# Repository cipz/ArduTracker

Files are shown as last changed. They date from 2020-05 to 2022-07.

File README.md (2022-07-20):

# ArduTracker



#### Developers

- Ciprian Voinea
- Federico Carboni
- Mariano Sciacco
- Prof. Palazzi

# Board

### Esp32 Circuit board

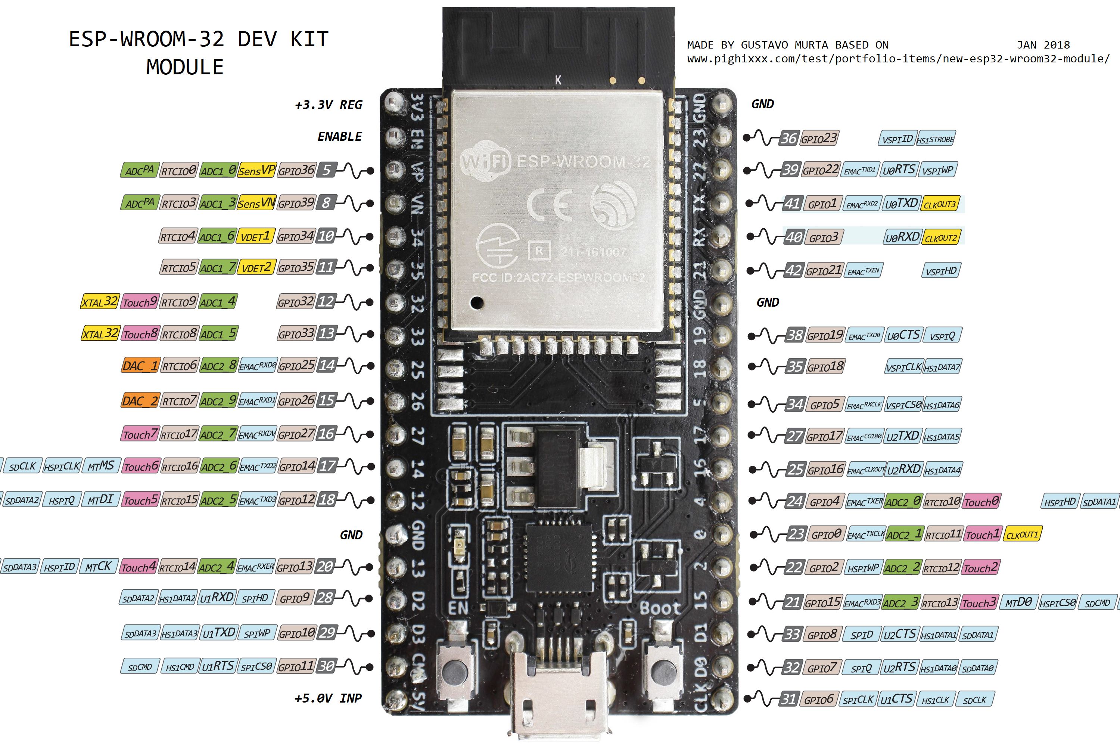
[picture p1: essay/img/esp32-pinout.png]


### Firmware

Arduino IDE + Platformio

#### Additional libraries
- [ArduinoJSON v6](https://arduinojson.org/v6/)

### Circuit

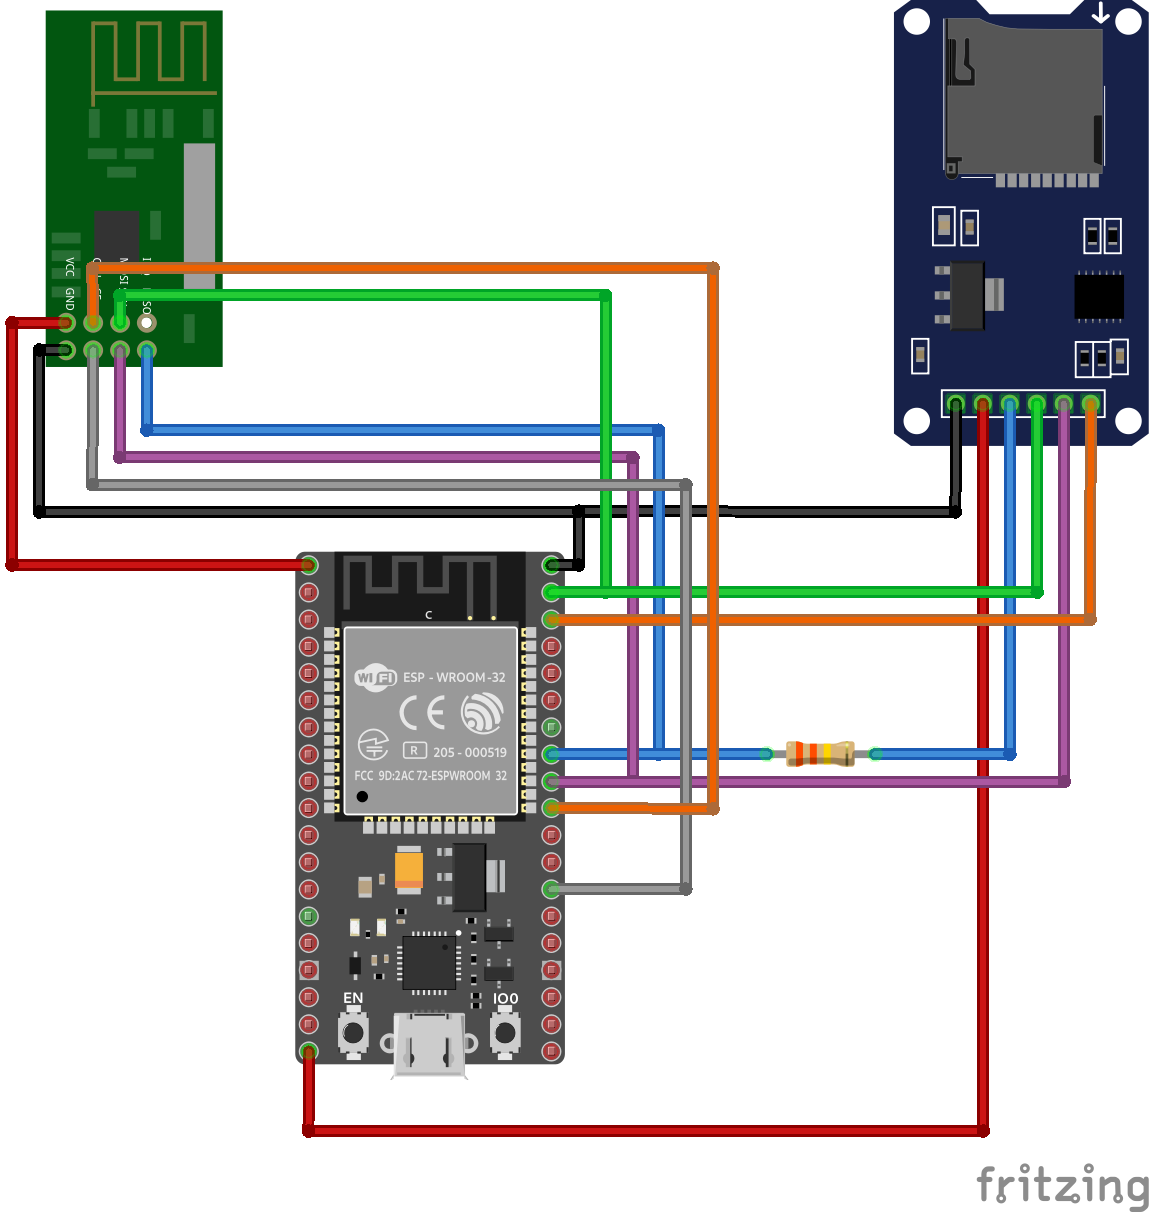
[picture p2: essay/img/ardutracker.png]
circuit


### SPI devices

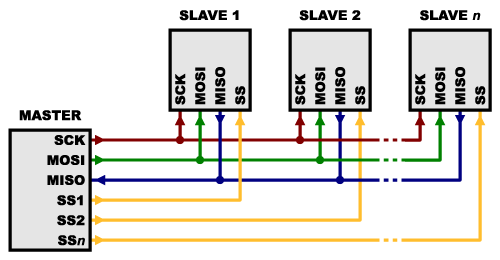
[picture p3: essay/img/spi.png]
spi


### Connecting nRF24L01 to the ESP32

<p align="center">
  <table align="center">
    <tr>
      <td>
        <table style="text-align:center">
          <tr style="font-weight: bold;">
            <td>nRF24L01</td>
            <td>ESP32</td>
          </tr>
          <tr>
            <td>GND</td>
            <td>GND</td>
          </tr>
          <tr>
            <td>VCC</td>
            <td>3.3V</td>
          </tr>
          <tr>
            <td>CE</td>
            <td>D4</td>
          </tr>
          <tr>
            <td>CSN</td>
            <td>D5</td>
          </tr>
          <tr>
            <td>SCK</td>
            <td>D18</td>
          </tr>
          <tr>
            <td>MOSI</td>
            <td>D23</td>
          </tr>
          <tr>
            <td>MISO</td>
            <td>D19</td>
          </tr>
        </table>
      </td>
      <td>
        <p align="center">
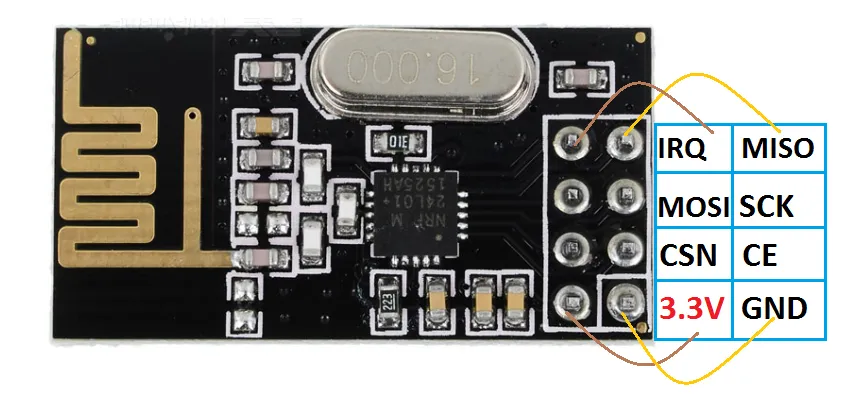
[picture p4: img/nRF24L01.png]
          
        </p>
      </td>
    </tr>
  </table>
</p>

### Connecting MicroSD Module to the ESP32

To connect the SD Module I have adapted a simple Arduino example:

<p align="center">
  <table align="center">
    <tr>
      <td>
        <table style="text-align:center">
          <tr style="font-weight: bold;">
            <td>MicroSD Module</td>
            <td>ESP32</td>
          </tr>
          <tr>
            <td>GND</td>
            <td>GND</td>
          </tr>
          <tr>
            <td>VCC</td>
            <td>5V or 3.3V</td>
          </tr>
          <tr>
            <td>CS</td>
            <td>D22</td>
          </tr>
          <tr>
            <td>SCK</td>
            <td>D18</td>
          </tr>
          <tr>
            <td>MOSI</td>
            <td>D23</td>
          </tr>
          <tr>
            <td>MISO</td>
            <td>D19</td>
          </tr>
        </table>
      </td>
      <td align="center">
        <p align="center">
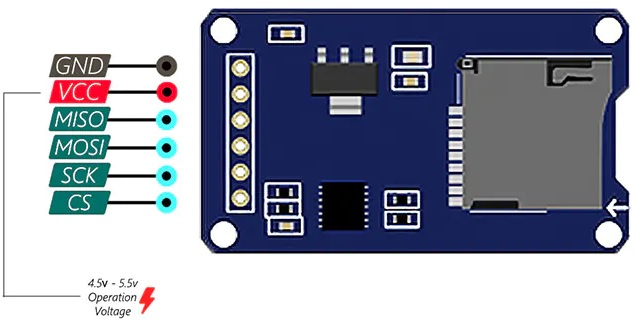
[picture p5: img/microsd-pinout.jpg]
          
        </p>
      </td>
    </tr>
  </table>
</p>

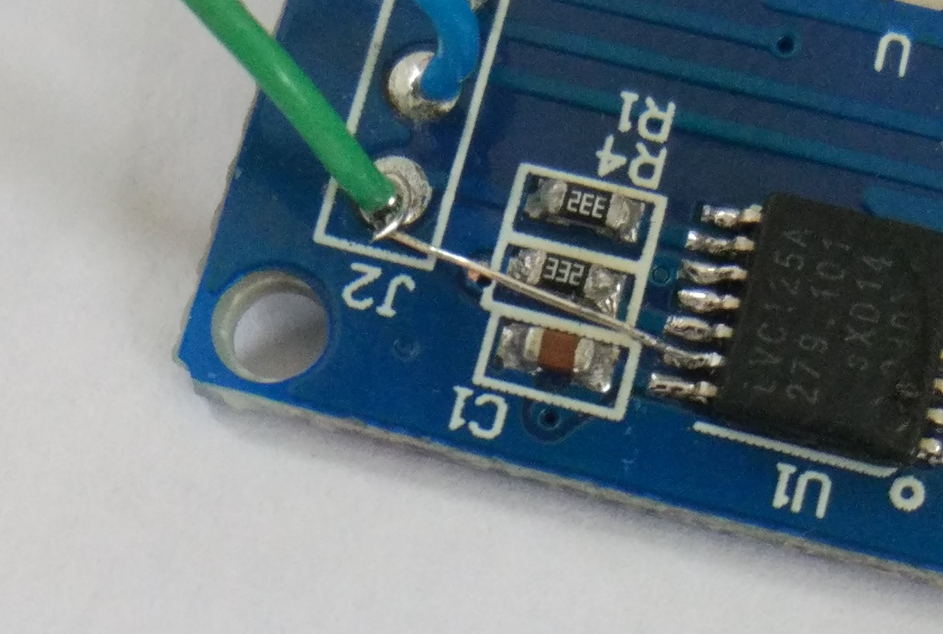
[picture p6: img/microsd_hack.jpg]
Microsd-hack


# Server

## Raspberry Pi and MQTT server
The Mosquitto MQTT server can be set on a Raspberry Pi in the network and it uses IBM's Node-Red.
To configure it I have followed [this](https://randomnerdtutorials.com/esp32-mqtt-publish-subscribe-arduino-ide/) tutorial.

## Docker

To setup the entire server part of the ardutracker project, you need to have installed Docker with docker-compose in a x86_64 capable machine with at least 1GB of ram a single core CPU. 

Move to the `/ArduTrackerServer/` directory and type in a terminal `docker-compose up -d`.
After that, you can stop all the services using `docker-compose down`, always in the same directory.

### Useful links:

#### Tutorials
- [Communication nRF24L01 avec cartes ESP32 et ESP8266 ](http://electroniqueamateur.blogspot.com/2019/12/communication-nrf24l01-avec-cartes.html?m=0)
- [Interfacing Micro SD Card Module with Arduino](https://lastminuteengineers.com/arduino-micro-sd-card-module-tutorial/)
- [ESP32 MQTT – Publish and Subscribe with Arduino IDE](https://randomnerdtutorials.com/esp32-mqtt-publish-subscribe-arduino-ide/)

#### Circuit
- [ESP32 Fritzing file](https://forum.fritzing.org/t/esp32s-hiletgo-dev-boad-with-pinout-template/5357?u=steelgoose)

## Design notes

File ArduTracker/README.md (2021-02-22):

# Project Notes

- SD card adapter requires 5v instaed of 3.3volt, otherwise it does not work properly ([Issue reference](https://rntlab.com/question/card-mount-failed/))

### Debugging MQTT

- Install this software on your PC and connect to mqtt://ardutracker.debug.ovh:21883 ([Mqtt Explorer](http://mqtt-explorer.com/))

#### Upload ports in MacOS

Ignore this, just for developers:

- usb 2: `pio run -t upload --upload-port /dev/cu.usbserial-0001`

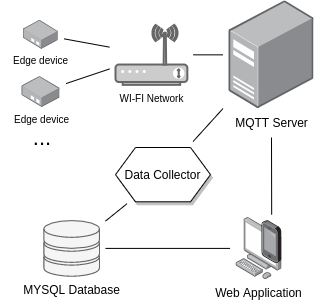
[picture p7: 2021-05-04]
essay/schemas/architecture-schema.png

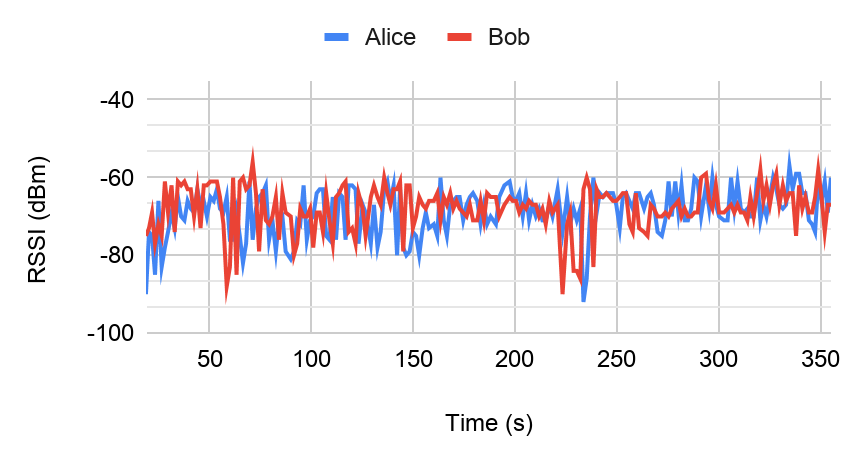
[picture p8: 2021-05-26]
essay/img/ble-indoor-5m.png

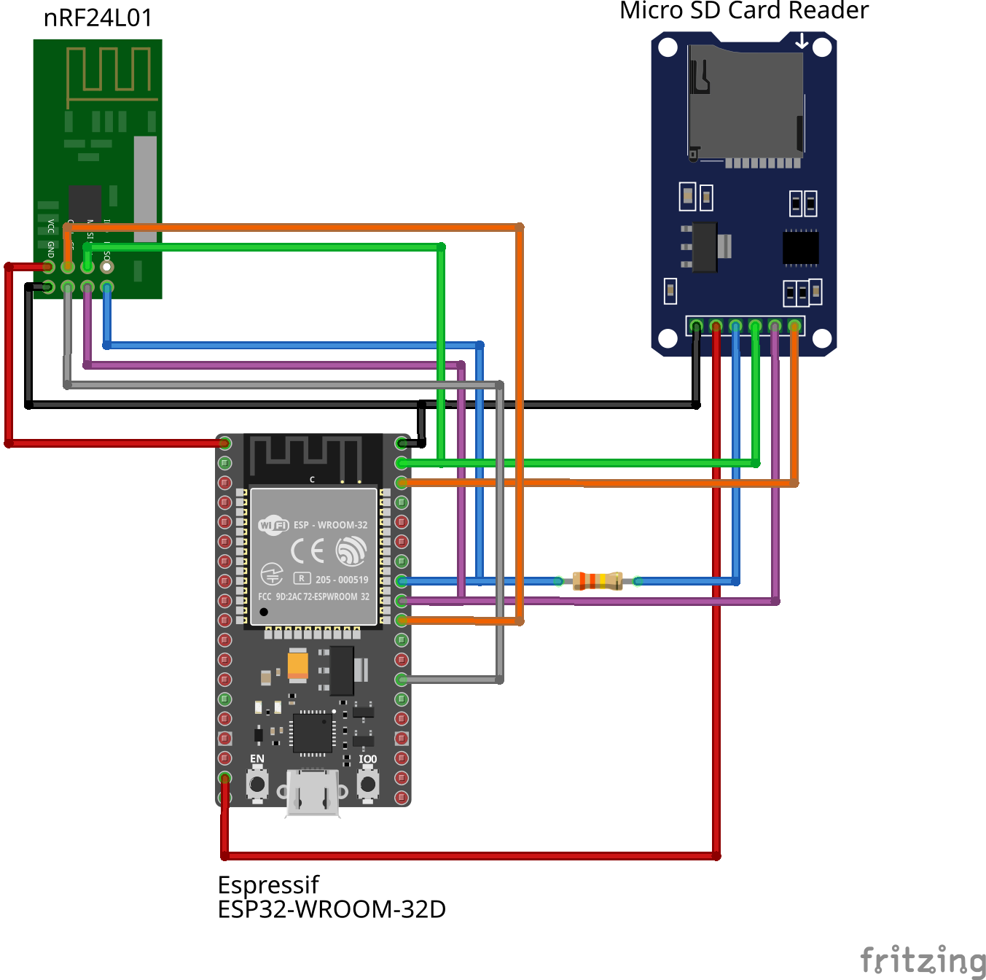
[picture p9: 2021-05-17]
essay/img/ardutracker-label.png

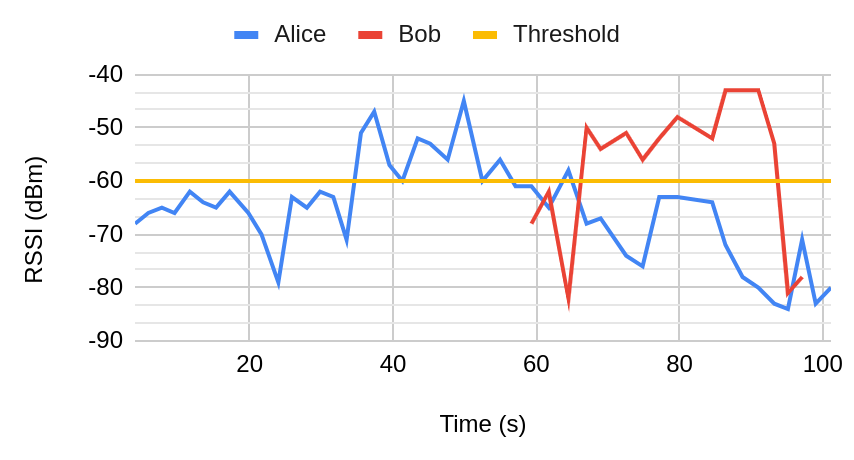
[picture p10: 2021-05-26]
essay/img/ble-moving-station-indoor-outdoor.png

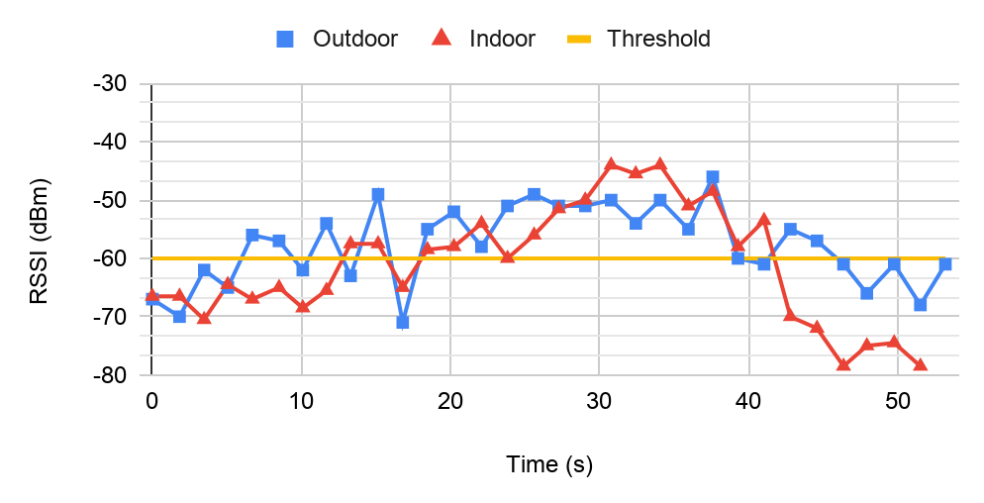
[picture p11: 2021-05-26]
essay/img/ble-sta-moving.png

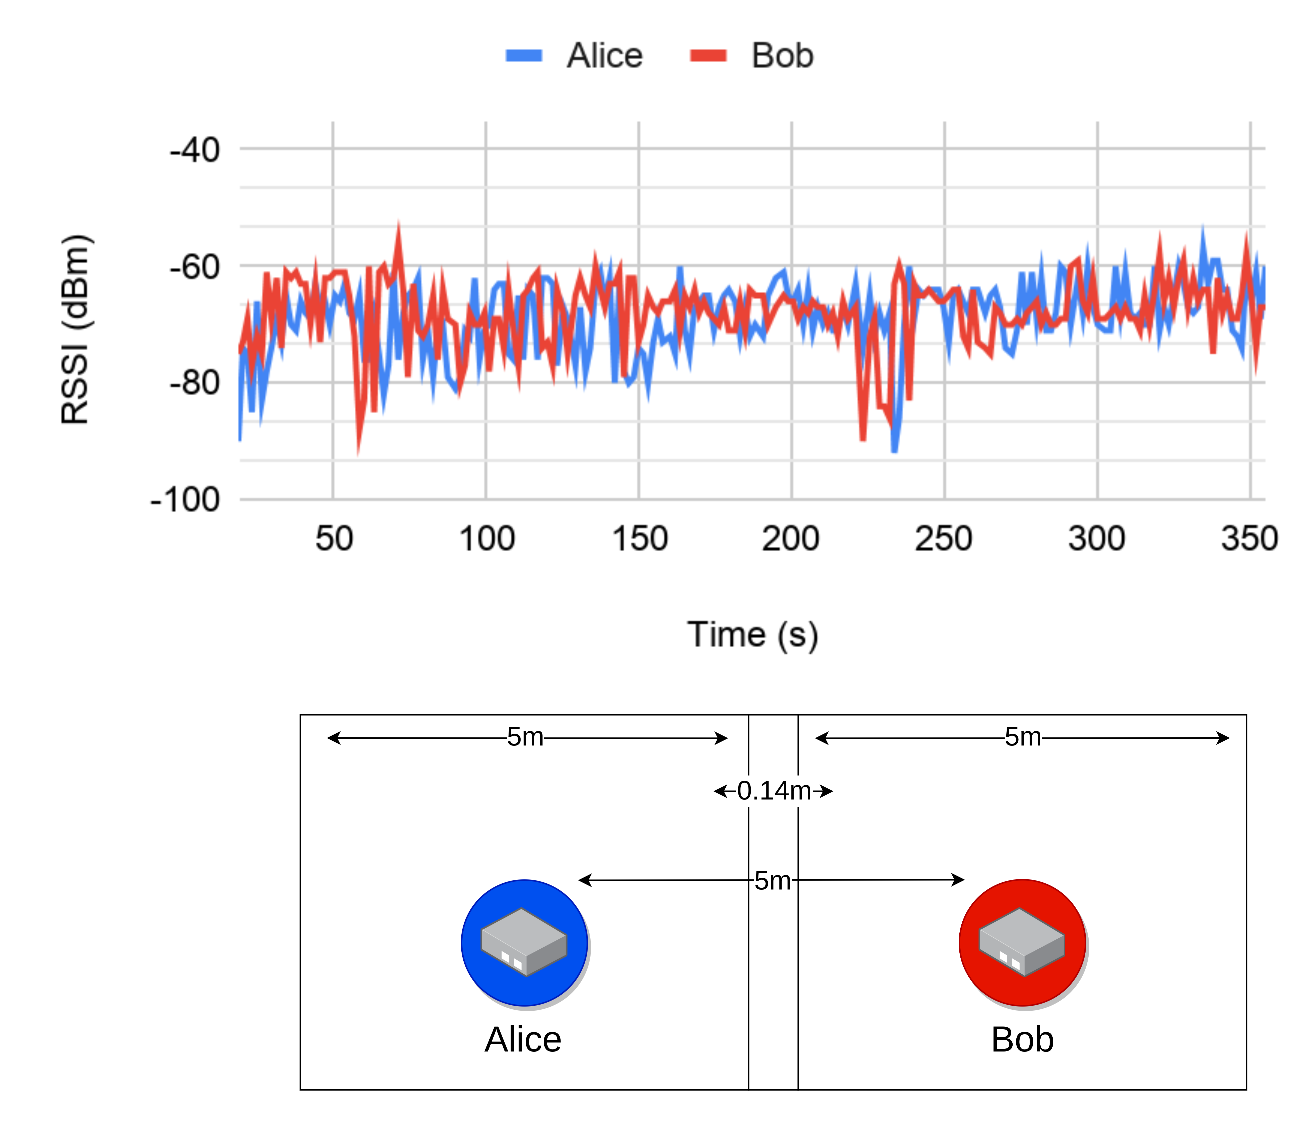
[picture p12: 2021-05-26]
essay/schemas/graph-5m-indoor-ble.png

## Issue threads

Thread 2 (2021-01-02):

Componenti di progetto (backend server + frontend)

Maxelweb, 2021-01-02:
## Link utili

**Link PHPMyAdmin**: http://phpmyadmin.ardutracker.debug.ovh
**Connessione Database**: http://database.ardutracker.debug.ovh:3306
**Link Ardutracker**: http://ardutracker.debug.ovh
**Link Portainer (Docker)**: http://portainer.ardutracker.debug.ovh

## Lista dei componenti

- [x] MQTT server su un container docker
- [x] Generatore di messaggi randomici sul server MQTT
- [x] MQTT subscriber per salvare i messaggi dal topic al database
- [x] Interfaccia grafica (da decidere insieme il tipo di framework, etc.)
- [x] Database MYSQL

## Database

**User**: `admin_ardutrack`
**Password**:  `1q9p7lETVi`
**Database**: `ardutrackerdb`
**IP**: `database.ardutracker.debug.ovh`

## Mosquitto (MQTT server broker)

**Listener:** ardutracker.debug.ovh:21883
**Extra-listener:** ardutracker.debug.ovh:29001

Closed 2022-07-20.

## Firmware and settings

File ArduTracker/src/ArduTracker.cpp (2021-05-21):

/*
 *  ARDUTRACKER BOARD (2020 - 2021)
 *  -----------------
 *  Wireless Networks for mobile applications, UniPD
 *  --------
 *  Created by Ciprian Voinea
 *  Edited by Federico Carboni and Mariano Sciacco
*/

// --------------------------------------- Static config

#define RANDOM_TX_MILLS_MIN 2000
#define RANDOM_TX_MILLS_MAX 4000
#define RANDOM_RX_MILLS_MIN 3000
#define RANDOM_RX_MILLS_MAX 6000
#define SERIAL_BAUD_RATE 9600
#define MAX_WIFI_RECON_COUNT 5
#define RESTART_SECONDS 10
#define BLE_PREFIX "AT_"

// Debug modes

#define DEBUG_MODE 1
#define SD_DEBUG_MODE 0
#define STATS_DEBUG_MODE 1

// --------------------------------------- Initialization

#include <SPI.h>
#include <PubSubClient.h>
#include <time.h>
#include <ArduinoJson.h>
#include <LinkedList.h>
#include <WiFi.h>

bool wifiTransmission;
int lastWifiSendTime;
int sendDataCount;

struct Params {
  // WiFi
  char ssid[50];
  char password[50];
//   int wifi_send_interval;
  // nRF24L01
  char my_id[15];
  byte broadcast_io_addr[15];
  // MQTT
  char in_topic[32];
  char out_topic[32];
  char mqtt_server[32]; //FIX: Expanded to allow hostnames
  // Other
  int friendly_freshness;
  // Radio mode
  char radio_mode[15];
  bool station_mode;
  int send_data_cycles;
  int ble_threshold;
  int wifi_kbps;
  int scan_duration;
  int cycles_delay;
};
Params params;
double stats[2] = {0, 0};

WiFiClient espClient;
PubSubClient client(espClient);

#include "at_log.h"
#include "at_utils.h"
#include "abstract_radio.h"
#include "at_nrf24l01.h"
#include "at_ble.h"
#include "at_wifi.h"

LinkedList<Log>* friendList;
#include "at_sd.h"

SDController* sdCrtl;
#include "at_mqtt.h"

AbsRadioController* radioCtrl;
WiFiController* wifiCtrl;
MQTTController* mqttCtrl;


// --------------------------------------- Initial Setup
void setup() {
    Serial.begin(SERIAL_BAUD_RATE);
    Serial.println("Booting device...");

    pinMode(CS_PIN, OUTPUT);
    pinMode(CE_PIN, OUTPUT);

    friendList = new LinkedList<Log>();

    sdCrtl = new SDController();
    wifiCtrl = new WiFiController();
    mqttCtrl = new MQTTController();

    sdCrtl->init();
    sdCrtl->listContent();
    sdCrtl->acquireParams();
    sdCrtl->initLog();
    SDController::populateFromCache();
    delay(100);

    // Mode switcher 
    if(strcmp(params.radio_mode, "WIFI") == 0)
        radioCtrl = new RadioController();
    else if(strcmp(params.radio_mode, "BLE") == 0)
        radioCtrl = new BLEController();
    else {
        Serial.print("Radio mode not found! Using Radio WIFI as default..");
        strlcpy(params.radio_mode, "WIFI", sizeof(params.radio_mode));
        radioCtrl = new RadioController();
    }

    radioCtrl->init();
    wifiCtrl->init();
    mqttCtrl->init();
    sendDataCount = 0;

    Serial.println("Boot sequence finished correctly!");
    delay(100);
}

// --------------------------------------- Loop operations
void loop() {

    stats[0]=0, stats[1]=0;

    Serial.println("\n\n-- -- -- NEW LOOP CYCLE -- -- --\n");

    if(SD_DEBUG_MODE) 
        sdCrtl->listContent();

    //-------------------- Connect to WiFi and reach new Configuration
    
    wifiCtrl->connect();
    mqttCtrl->connect();
    
    if(WiFi.isConnected() && !mqttCtrl->isSubscribed()) {
        // Subscribe to params configuration topic
        String configTopic = params.in_topic + WiFi.macAddress();
        mqttCtrl->subscribe(configTopic.c_str(), sdCrtl);
        Serial.printf(
            "\nSubscribed to: %s\n", 
            configTopic.c_str());
    }


    //-------------------- Send data to MQTT

    if(WiFi.isConnected() && sendDataCount >= params.send_data_cycles) {
        
        Serial.printf(
            "\nSending from CACHE to %s with topic %s", 
            params.mqtt_server, 
            params.out_topic);

        
        File sessionLogFile = SD.open(SESSION_FILE, FILE_READ);
        int inputChar = sessionLogFile.read();
        int strIndex = 0;
        char inputStr[512];

        Serial.println("\nSending:");

        while(inputChar != EOF) {
            if(inputChar != '\n') {
                inputStr[strIndex] = inputChar;
                strIndex++;
                inputStr[strIndex] = '\0';
            }
            else { // Each line
                Serial.println(inputStr);
                mqttCtrl->publish(params.out_topic, inputStr);
                delay(50);
                strIndex = 0;
            }
            inputChar = sessionLogFile.read();
        }

        Serial.printf("\nAll records have been sent to %s \n", params.mqtt_server);
        sessionLogFile.close();
        sdCrtl->clearFile(SESSION_FILE);
        sendDataCount = 0;
    }
    else {
        sendDataCount++;
    }

    // lastWifiSendTime = millis(); // unused

    // -------------------- Receive radio message
    LinkedList<Log>* tmpFriendList = radioCtrl->scan();

    if(DEBUG_MODE)
        Utils::printList(friendList, "[DEBUG-BEFORE]");
    Utils::updateFriendList(friendList, tmpFriendList);
    if(DEBUG_MODE)
        Utils::printList(friendList, "[DEBUG-AFTER]");
   
    // -------------------- Save list to SD 

    Serial.print("Saving exposure sessions to SD . . . \n");

    String serializedMsg = "";
    
    if(friendList->size() > 0) {

        for(int i = 0; i < friendList->size(); ++i){
            if(friendList->get(i).is_from_cache || difftime(time(nullptr), friendList->get(i).last_exposure_time) * 1000 > params.friendly_freshness) {
                String msg = friendList->get(i).serializeMqtt(params.my_id);
                if(DEBUG_MODE)
                    Serial.println(msg);

                sdCrtl->saveConcludedSession(msg);
                friendList->remove(i);
                // Salvo in session e in perm
            }
            else {
                serializedMsg += friendList->get(i).serializeLocal() + "\n"; 
            }
        }

        sdCrtl->saveCurrentSessions(serializedMsg);
        Serial.print("Saved!");
    }
    else 
        Serial.print("Nothing new to save.");
    
    tmpFriendList->clear();

    //-------------------- Send radio message

    Serial.println(params.station_mode);
    if(!params.station_mode) {
        radioCtrl->send();
    }

    if(STATS_DEBUG_MODE) {
        Serial.printf("STATS: %d ---> %d \n", strcmp(params.radio_mode, "BLE"), radioCtrl->getStatsRx());

        if(strcmp(params.radio_mode,"WIFI") == 0)
            sdCrtl->saveInStats(radioCtrl->getStatsTx(), radioCtrl->getStatsRx());
        else if(strcmp(params.radio_mode, "BLE") == 0 && stats[0] && stats[1])
            sdCrtl->saveInStats(stats[0], stats[1]);
        //     sdCrtl->saveInStats(radioCtrl->getStatsRx());
    }
    
    if(DEBUG_MODE)
        Serial.printf("Cycles delay: %d \n", params.cycles_delay);
    delay(params.cycles_delay);
}

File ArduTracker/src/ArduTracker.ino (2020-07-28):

#define SERIAL_BAUD_RATE 9600
#define DEBUG_MODE 0
#define MAX_WIFI_RECON_COUNT 5
#define RESTART_SECONDS 10
#define RANDOM_TX_MILLS_MIN 2000
#define RANDOM_TX_MILLS_MAX 4000
#define RANDOM_RX_MILLS_MIN 3000
#define RANDOM_RX_MILLS_MAX 6000

#include <SPI.h>
#include <ArduinoJson.h>

#include <PubSubClient.h>
#include <time.h>

#include "at_utils.h"

#include "at_list.h"
List * friend_list;

struct Params {
  // WiFi
  char ssid[50];
  char password[50];
  int wifi_send_interval;
  // nRF24L01
  char my_id[15];
  byte broadcast_io_addr[15];
  // MQTT
  char in_topic[25];
  char out_topic[25];
  char mqtt_server[16];
  // Other
  int friendly_freshness;
};
Params params;

#include "at_nrf24l01.h"
#include "at_sd.h"
#include "at_wifi.h"

bool wifi_transmission;
int last_wifi_send_time;

WiFiClient espClient;
PubSubClient client(espClient);

// -- -- -- -- -- -- -- -- -- -- -- -- -- -- -- -- -- -- -- -- -- -- -- -- -- -- -- -- -- -- -- --

void setup() {

  Serial.begin(SERIAL_BAUD_RATE);
  Serial.println("Booting device");

  pinMode(CS_PIN, OUTPUT);
  pinMode(CE_PIN, OUTPUT);

  //\\//\\//\\//\\//\\//\\//\\//\\//\\//\\

  // SD setup
  Serial.print("Setting up SD card: ");

  if (init_sd())
    Serial.println("OK");
  else {
    Serial.println("ERROR");
    Serial.println("Rebooting in 10 seconds");
    restart(RESTART_SECONDS);
  }

  Serial.println("SD card contents: ");
  listFiles();

  Serial.print("Acquiring parameters from SD card: ");
  if (load_sd_params())
    Serial.println("OK");
  else {
    Serial.println("ERROR");
    Serial.println("Rebooting in 10 seconds");
    restart(RESTART_SECONDS);
  }

  Serial.println("Creating log files");
  init_log_files();
  Serial.println("Log files correctly created!");

  delay(100);

  //\\//\\//\\//\\//\\//\\//\\//\\//\\//\\

  // Radio setup
  Serial.println("Initializing radio functions");
  init_radio();

  //\\//\\//\\//\\//\\//\\//\\//\\//\\//\\

  // Received data list setup
  friend_list = new List();

  //\\//\\//\\//\\//\\//\\//\\//\\//\\//\\

  // WiFi + time
  Serial.println("Initializing WiFi");
  WiFi.mode(WIFI_STA);
  last_wifi_send_time = 1000000000;
  wifi_transmission = true;
  // timezone is 2
  configTime(2 * 3600, 0, "pool.ntp.org", "time.nist.gov");

  //\\//\\//\\//\\//\\//\\//\\//\\//\\//\\

  // MQTT
  Serial.println("Initializing MQTT");
  client.setServer(params.mqtt_server, 1883);

  //\\//\\//\\//\\//\\//\\//\\//\\//\\//\\

  if (DEBUG_MODE) {

    Serial.println("Initializing DEBUG_MODE variables");

    // Radio
    const byte broadcastAddress[5] = {'R', 'x', 'T', 'x', '0'};
    radio.openWritingPipe(broadcastAddress);
    radio.openReadingPipe(1, broadcastAddress);
    strlcpy(params.my_id, "IRON MAN", sizeof(params.my_id));
    params.friendly_freshness = 5000;

    // WiFi
    strlcpy(params.ssid, "NETGEAR66", sizeof(params.ssid));
    strlcpy(params.password, "elatedowl630", sizeof(params.password));
    wifi_transmission = false;

    // MQTT
    strlcpy(params.mqtt_server, "192.168.0.13", sizeof(params.mqtt_server));

  }

  Serial.println("Boot sequence finished correctly!");
  delay(100);

}

// -- -- -- -- -- -- -- -- -- -- -- -- -- -- -- -- -- -- -- -- -- -- -- -- -- -- -- -- -- -- -- --

void loop() {

  Serial.println("\n\n\n\n\n- - - - - NEW LOOP CYCLE\n");

  if (DEBUG_MODE) {
    Serial.println("SD card contents: ");
    listFiles();
  }

  // Generating random times
  int random_tx_time = random(RANDOM_TX_MILLS_MIN, RANDOM_TX_MILLS_MAX);
  int random_rx_time = random(RANDOM_RX_MILLS_MIN, RANDOM_RX_MILLS_MAX);

  // Serial.println("\n -- -- -- -- -- -- -- -- \n");

  // Radio receiving
  int start_rx_time = millis();
  radio.startListening();
  List * tmp_friend_list = new List();
  int rx_count = rx_data(random_rx_time, tmp_friend_list);

  Serial.print("Received ");
  Serial.print(rx_count);
  Serial.println(" messages");

  // -----------------------------------

  // Saving files to sd card
  Serial.println("friend_list->printNodes();");
  friend_list->printNodes();

  Serial.println("tmp_friend_list->printNodes();");
  tmp_friend_list->printNodes();

  Serial.println("removing duplicates from tmp_friend_list");
  tmp_friend_list->removeDuplicates();
  
  friend_list->appendList(tmp_friend_list);
  friend_list->compactList(params.friendly_freshness);

  Serial.println("tmp_friend_list->printNodes();");
  tmp_friend_list->printNodes();
  Node * tmp_friend = tmp_friend_list->first;
  while (tmp_friend) {

    if (WiFi.status() != WL_CONNECTED)
      tmp_friend->seen_time = time(nullptr);

    // Creating string to save in file
    String current_message = "{\
\"my_id\" : \"" + (String)params.my_id + "\", \
\"friend_id\" : \"" + (String)tmp_friend->friend_id + "\", \
\"seen_millis\" : \"" + (String)tmp_friend->seen_millis + "\", \
\"seen_time\" : \"" + (String)tmp_friend->seen_time + "\" \
}";

    Serial.println("Saving to sd card... ");
    Serial.println(current_message);
    save_in_log(current_message);

    Serial.println(tmp_friend->seen_millis);
    tmp_friend = tmp_friend->next;

  }

  // Removing tmp_list
  tmp_friend_list->deleteList();

  // -----------------------------------

  delay(50);

  Serial.println("\n -- -- -- -- -- -- -- -- \n");

  // Radio sending
  int start_tx_time = millis();
  radio.stopListening();
  Serial.print("Sending : '");
  Serial.print(params.my_id);
  Serial.println("'");
  int tx_count = tx_data(random_tx_time);
  Serial.print("Sent ");
  Serial.print(tx_count);
  Serial.println(" messages");

  Serial.println("\n -- -- -- -- -- -- -- -- \n");

  if (wifi_transmission) {
    // Sending messages over WiFi
    if (millis() - last_wifi_send_time > params.wifi_send_interval) {
      if (WiFi.status() != WL_CONNECTED) {

        Serial.println("Scanning available networks...");
        if (wifi_scan(params.ssid)) {

          Serial.println("Setting up WiFi connection.");
          int wifi_recon_count = 0;
          Serial.print("Attempting connection");
          while ((WiFi.status() != WL_CONNECTED) and (wifi_recon_count < MAX_WIFI_RECON_COUNT)) {
            Serial.print(".");
            WiFi.begin(params.ssid, params.password);
            wifi_recon_count++;
            delay(50);
          }

          if (wifi_recon_count < MAX_WIFI_RECON_COUNT) {
            Serial.println("WiFi connected successfully");
            Serial.print("IP address: ");
            Serial.println(WiFi.localIP());
          } else {
            Serial.println("Exceeded connection tries");
          }

        } else {
          Serial.print(params.ssid);
          Serial.println(" not in range.");
        }
      } else {
        Serial.println("WiFi already connected");
      }

      if (WiFi.status() != WL_CONNECTED) {
        Serial.print("Error connecting to ");
        Serial.println(params.ssid);

      } else {

        Serial.print("Connected to ");
        Serial.println(params.ssid);

        // -----------------------------------
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

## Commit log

2020-05-03 Added circuit
    [ArduTracker.fzz]
2020-05-05 Updated circuit
    [ArduTracker_Arduino_UNO.fzz, ArduTracker_esp32.fzz]
2020-05-05 Circuit fix
    [ArduTracker_esp32.fzz]
2020-05-06 Solved SD problem (add / in front of files)
    [ArduTracker.ino]
2020-05-07 VCC of MicroSD to 3.3V
    [ArduTracker_esp32.fzz]
2020-05-07 Removed UNO circuit
    [ArduTracker_Arduino_UNO.fzz]
2020-05-09 Trying to fix problems with SD Card
    [ArduTracker.ino]
2020-05-17 Double Linked List not working
    [ArduTracker.ino]
2020-07-28 write on sd not working
    [ArduTracker.ino]
2021-02-02 Edit circuit composition
    NOTE: On the 3.3v SD card cannot be read, use the 5v instaed.
    IMPORTANT: Make sure the red led in the ESP is ON after connecting the power. Otherwise, turn it off immediatly and check the cables or something might start burning.
    [ArduTracker_esp32.fzz]
2021-02-19 Code correction and new list implementation #9
    Note: if the two cycles of the prototypes are randomically semi-syncronized, one received more message than the other. A small trick would be to implement a random timer between packet sending, like the Aloha protocol, to obtain a more balance packet reception.
    (Commit done together with @Kero2375 via live share VS Code)
    [ArduTracker.cpp]
2021-02-21 Fix a wrong String print in the serial console, add comments in every file
    [ArduTracker.cpp]
2021-02-21 Add random timer in tx and rx, add stats file
2021-02-22 Fix msg sent in mqtt, fix db
    [ArduTracker.cpp]
2021-02-24 Add boards page in server
2021-02-24 Add and complete boards page
2021-02-26 Fix millis constructor for datetime
2021-02-28 First BLE test
    The board now works just as Server: we could switch to Client mode for a random time.
    Changing the board partition table in `platformio.ini` allows us to use more memory for the code
2021-03-09 #23 Add filters and search
2021-03-11 Added radio mode switcher Change the `radio_mode` field inside the SD file `params.json` (supported "BLE" and "NRF24") #20
2021-03-14 Add clear filter toggle
2021-03-14 Add boards registration
2021-03-14 Add prettier, add board reg logic and config view
2021-03-14 Fix Boards list
2021-03-14 Fix board detail and edit
2021-03-14 Board mqtt subscriber for params edit
2021-03-16 Update board details
2021-03-16 Add business-logic to board update in db
2021-03-19 Refactor and algorithm update Not working: friendList elements does not updates
    [ArduTracker.cpp]
2021-03-20 Fix dependency with arduinoJson
    [ArduTracker.cpp]
2021-03-21 Fix seen_time calculation Now it uses just time_t instead of millis since boot
    [ArduTracker.cpp]
2021-03-21 Add logic password protection, add error messages, fix boards no id
2021-03-21 Add search by ID in Boards
2021-03-21 Fix typos in sql db 😒
2021-03-21 Fix boards my_id and mqtt listener
2021-03-21 Fixed BLE name not always seen
    [ArduTracker.cpp]
2021-03-25 Fixed session duration time Using `start/end_millis` and `last_seen_time` All recovered sessions from cache are saved and sent
    [ArduTracker.cpp]
2021-03-28 Fix filter and version
2021-03-28 Add type and mode in boards list
2021-04-05 Update config with new default board config
2021-04-06 Add extra info config for board variables, add docs
2021-04-29 Update final circuit
    [ArduTracker_esp32.fzz]
2021-05-17 labelled circuit
    [ArduTracker_esp32.fzz]
2021-05-17 Add case study workflow
2021-05-17 case-study-schema edited
2021-05-18 Case study workflow update with server
